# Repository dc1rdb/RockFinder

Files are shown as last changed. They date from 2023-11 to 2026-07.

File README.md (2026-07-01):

## Updates and Project Log
June 30, 2026: Support for Optional Bluetooth module

An optional HC-05 or JDY-33 BT module will allow to transmit CPS data to CurieFinder https://github.com/ATonda/CurieFinder_app
CurieFinder is a field tool designed for localization of radiation sources, mapping areas with elevated activity, prospecting and tracing ore veins.
Latest Arduino sketch located here: https://github.com/dc1rdb/RockFinder/blob/main/software/Rockfinder_digital/Rockfinder_digital.ino

June 26, 2026: Full digital version finally working

The full digital version is finally working satisfactory. The below mentioned analog circuit is no longer required, TTL output of Mini SiD directly connects to GPIO13 (D7 on Wemos D1 mini). Optional sensitivity adjustment via rotary encoder. 

July 30, 2024: Code changes V3.0

- Rotary encoder readout now via ISR
- Real variable gain rather than just threshold adjustment

Dec 8th, 2023: Update 

I`ve just finished a unit that incorporates a rotary encoder for threshold adjustment and utilizes a 40 mm dia x 40 mm NaI(Tl) scintillator coupled to a 2x2 SiPM array (MICROFC-60035-SMT-TR). With around four times the scintillator volume compared to my first unit, the sensitivity is significantly improved. A few pics of the new unit can be found in https://github.com/dc1rdb/RockFinder/tree/main/docs

# RockFinder
Scintillator based detector for prospecting radioactive minerals.
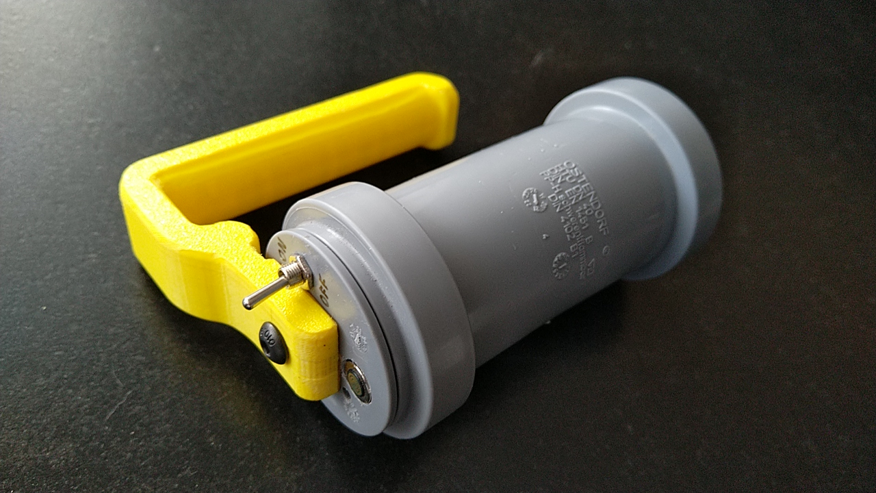
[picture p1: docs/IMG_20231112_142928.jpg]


## Background
When searching for radioactive rocks in the wild, I always found it annoying to keep my eyes on the display of whatever gamma detector I was using. Concentrating on small changes in click rate is also less than ideal.
On the other hand, the human brain / ear can easily and subconciously detect very small variations in tone pitch. For example, this principle is widely used in satellite dish alignment tools.

## Project Overview
This project is an add-on for **Nuclear Phoenix' Mini SiPM Driver (SiD) Board:** https://github.com/OpenGammaProject/Mini-SiD

Please refer to his page for setting up the scintillator and SiPM.

This add-on converts the TTL output pulses from the Mini SiD to a tone signal with variable frequency. The tone frequency increases with the count rate detected by the SiPM. As a result, one can quickly pinpoint the radioactive source / hotspot.

## Specs

* Compact design: Total size 125 x 100 x 55 mm. Weight 275 g
* Low-voltage device: No HV needed like with a photomultiplier tube
* Low power consumption: <50 mA
* Adjustable threshold / sensitivity to cope with different levels of background radiation (optional)

I am currently using a 1" dia x 1" CsI(Tl) encapsulated scintillator from OST Photonics, coupled to a MICROFC-60035-SMT-TR SiPM. The side wall of the scintillator is covered with lead foil to improve directivity.

## Description

Via a few additional passive components, the Trigger/TTL output of the Mini SiD is connected to the analog input of a ESP 8266 programmed as a voltage controlled oscillator. 

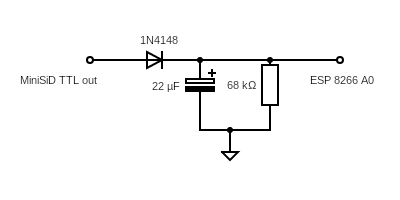
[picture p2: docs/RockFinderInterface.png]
RockFinderInterface


A passive buzzer connected to a GPIO pin of the ESP8266 outputs a tone signal.

Optionally, sensitivity can be adjusted with a rotary encoder.

The ESP8266 is a Lolin D1 Mini Pro with included battery connector and charging circuit. A small single cell 350 mAh LiPo battery sits between the Mini SiD and the veroboard and the Mini SiD is easily being powered via the 3V3 pin of the ESP. This allows for around 6 hours of operation. The LiPo battery is being charged via the USB interface of the ESP8266. A magnetic USB plug is added for better handling. If an internal battery is not required, any ESP8266 clone can be used.

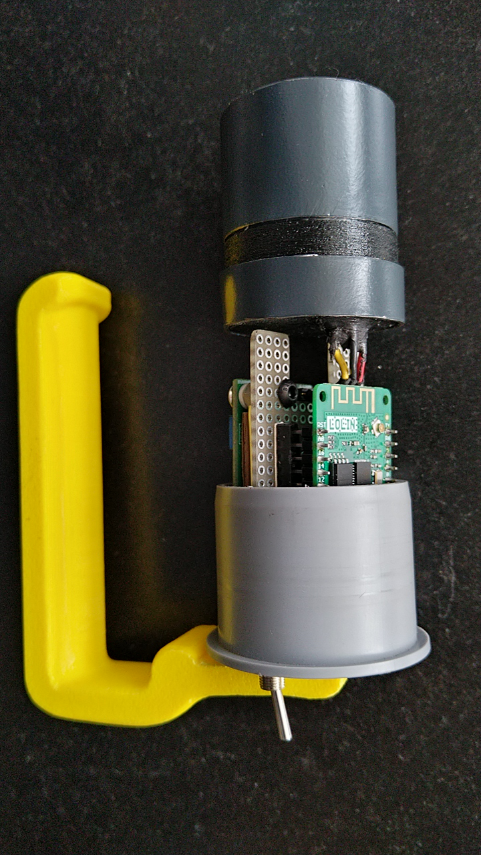
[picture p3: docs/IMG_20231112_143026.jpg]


## Hardware
The enclosure is a standard DN40 (or DN50) tube with end caps, available at home improvement stores. The handle is 3D printed from:
Ludlum 2401 Handle by S0N1C https://www.thingiverse.com/thing:2561532

An endcap to house the SiPM on the window side of the scintillator can be 3D printed with TPU from this file: https://github.com/dc1rdb/RockFinder/blob/main/hardware/SiPM_endcap1inch.stl

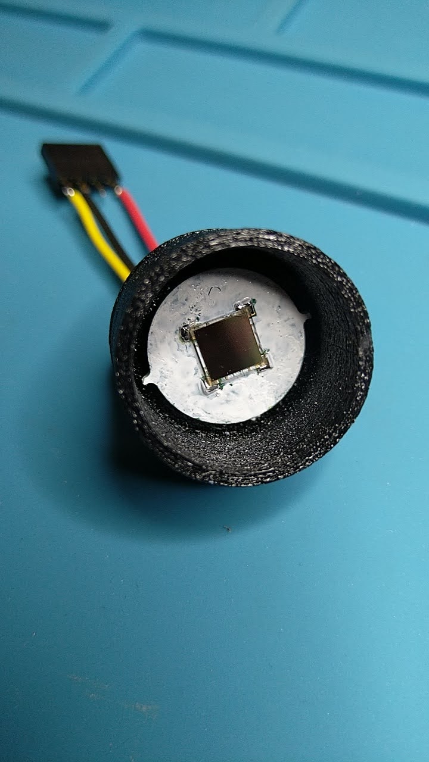
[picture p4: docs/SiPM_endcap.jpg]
SiPM_endcap


## Code
Arduino code in https://github.com/dc1rdb/RockFinder/tree/main/software/RockFinder_analog

## Demo
Video of the prototype in action: https://github.com/dc1rdb/RockFinder/blob/main/docs/RockfinderDemo.mp4

Thanks for reading!

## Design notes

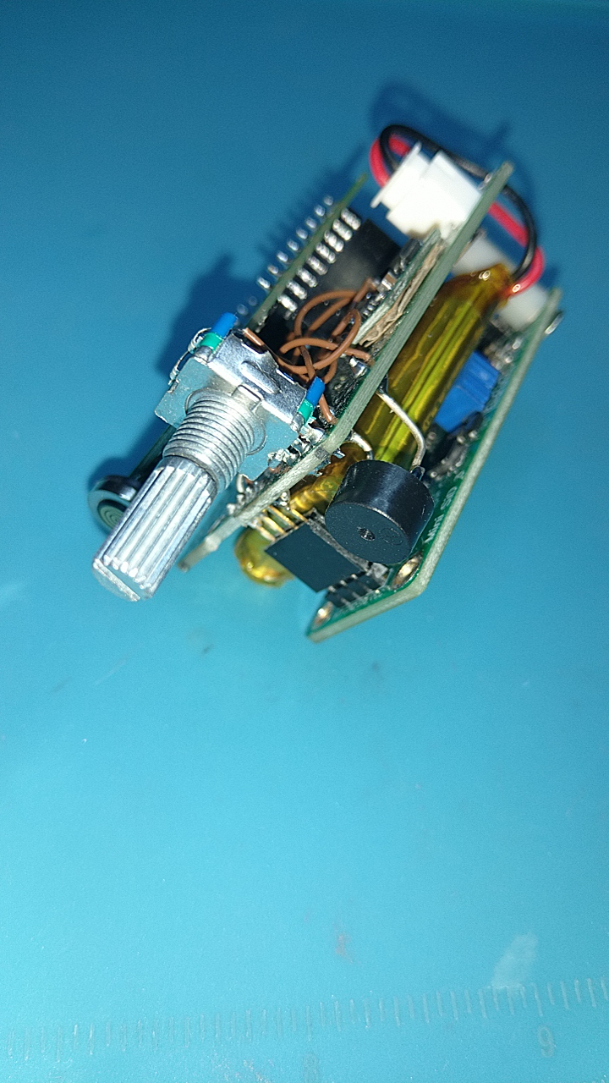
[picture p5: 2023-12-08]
docs/V2_internal1.jpg

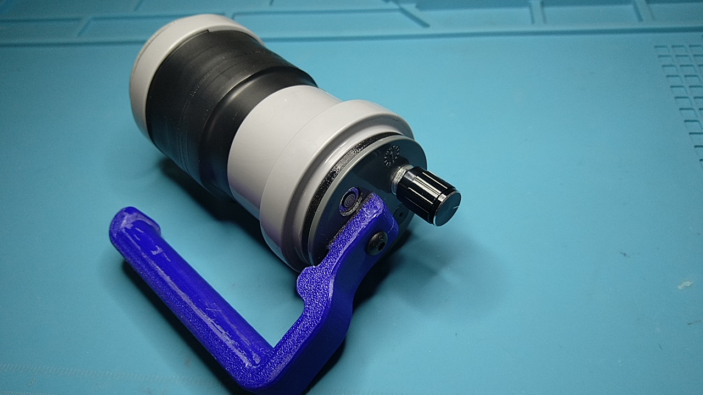
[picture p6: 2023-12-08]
docs/V2_external.jpg

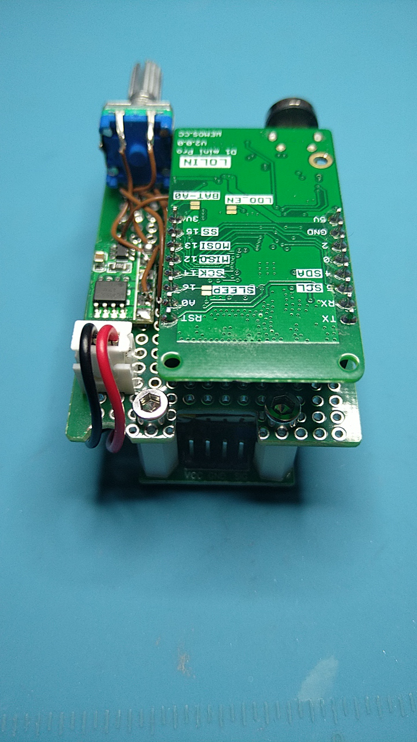
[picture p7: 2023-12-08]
docs/V2_internal2.jpg

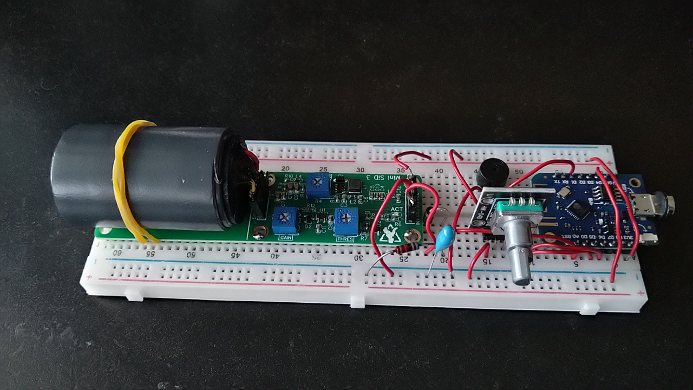
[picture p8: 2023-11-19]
docs/development_unit.jpg

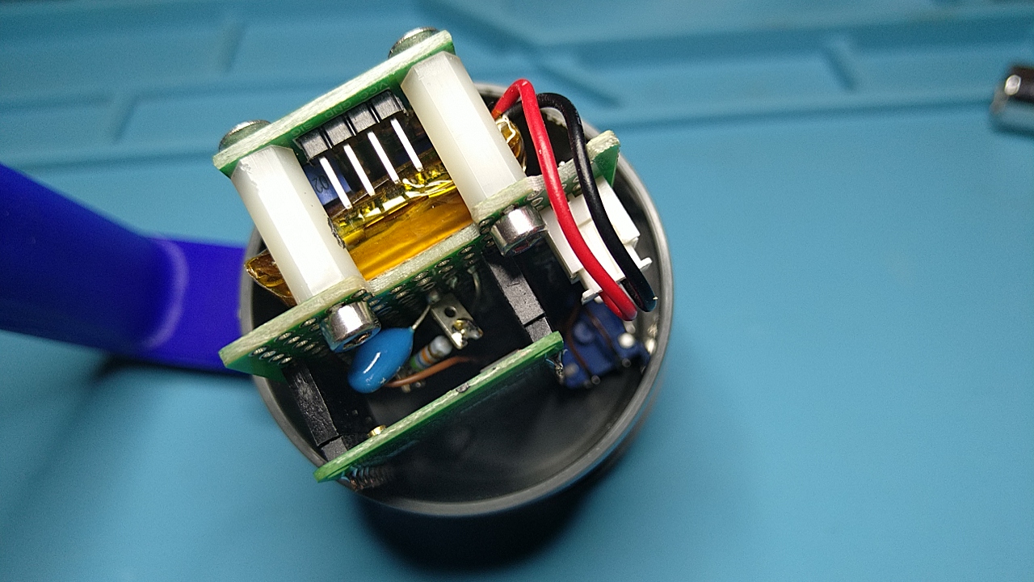
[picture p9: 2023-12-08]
docs/V2_internal3.jpg

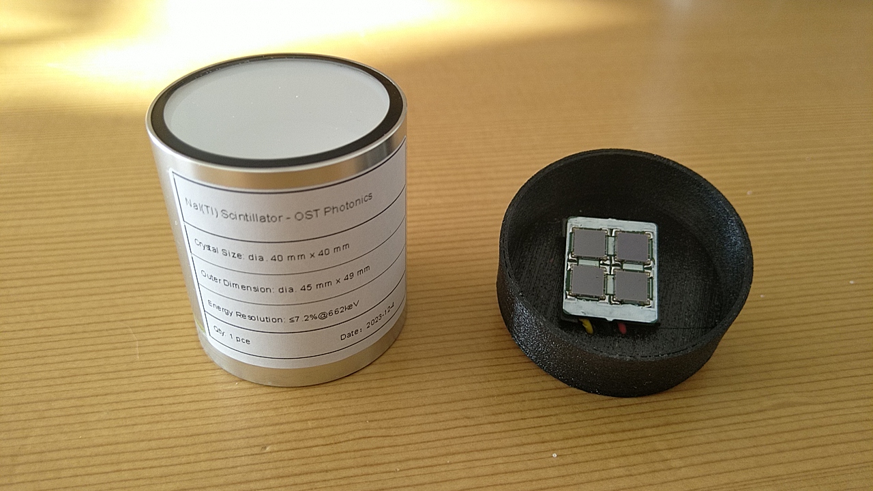
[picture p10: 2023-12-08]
docs/V2_scintillator_and_SiPM_array.jpg

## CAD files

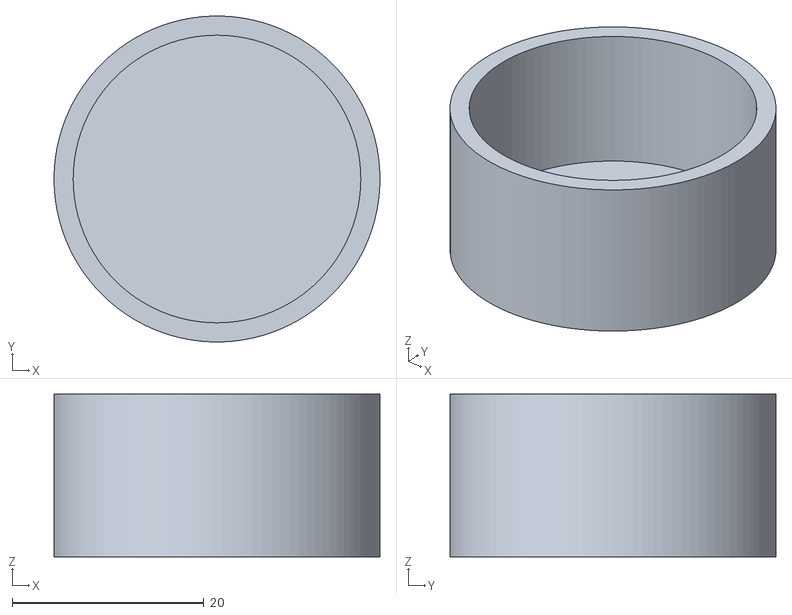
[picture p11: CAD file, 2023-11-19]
hardware/SiPM_endcap1inch.stl
34.0 x 34.0 x 17.0

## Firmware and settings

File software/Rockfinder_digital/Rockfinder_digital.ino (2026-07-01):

/*

Simple detector for gamma radioactive substances,
utilizing a Mini SiPM Driver (SiD) Board https://github.com/OpenGammaProject/Mini-SiD
and a Wemos D1 Mini ESP8266.
Converts Mini-SiD TTL output pulses to continuous moving tone
Optional rotary encoder for sensitivity adjustment
Optional HC-05 or JDY-33 BT module: connect RX to GPIO2  (D4 on Wemos D1 mini)
to transmit CPS data to CurieFinder https://github.com/ATonda/CurieFinder_app

V1.5 - Transmit battery voltage to CurieFinder (solder bridge on Wemos D1 mini required)
     - More filter optimizations

*/

#include <ESP8266WiFi.h>
#include <Arduino.h>

// ============================================================================
// 1. HARDWARE & CONSTANT SETUP
// ============================================================================
const int PULSE_PIN = 13;      // GPIO13 (D7 on Wemos D1 mini)
const int BUZZER_PIN = 5;       // GPIO5  (D1 on Wemos D1 mini)
const int BATTERY_PIN = A0;     // Analog pin A0 for voltage sensing

// Rotary Encoder Pins
const int encoderCLK = 14;     // GPIO14 (D5 on Wemos D1 mini)
const int encoderDT = 12;      // GPIO12 (D6 on Wemos D1 mini)

// HC-05 BT module RX on GPIO2  (D4 on Wemos D1 mini)

// Timing Rules
const unsigned long UPDATE_INTERVAL = 100;    //how often cps value is being calculated
unsigned long lastUpdateTime = 0;

// Bluetooth Timing Configuration
const unsigned long BT_INTERVAL = 200;       //how often data is being sent via Bluetooth
unsigned long lastBTTime = 0;             

// Global storage for the latest averaged value to share across loops
float globalFilteredCPS = 0.0;

// ============================================================================
// 2. SIGNAL FILTER & CONTROL CONFIGURATION
// ============================================================================
// Adaptive EMA Configuration
float emaFilteredCPS = 0.0;        
const float ALPHA_MIN = 0.05f;          //smoothing coefficient for stable baselines
const float ALPHA_MAX = 0.50f;          //response coefficient for rapid spikes
const float SENSITIVITY_SCALE = 0.007f;  //controls how aggressively alpha reacts to deviation

// Buzzer Frequency Boundaries (Hz)
const int MIN_FREQ = 30;                 //buzzer frequency at background radiation
const int MAX_FREQ = 5000;               //max buzzer frequency 

// Audio Glide Engine Constants
const float PITCH_GLIDE = 0.01f;        //"flywheel" for tone pitch changes
float targetPitch = MIN_FREQ;           
float activePitch = MIN_FREQ;           
int lastEmittedPitch = 0;            

// Dynamic Sensitivity Tuning
const int MIN_CPS = 50;              //background cps, higher value for larger scintillator     
volatile int maxCPSCeiling = 1000;   //adjust this for desired fixed sensitivity if no rotary encoder used
const int MIN_CEILING = 1000;        
const int MAX_CEILING = 15000;      
const int ENCODER_STEP = 1000;       

// Interrupt Storage
volatile unsigned long pulseCount = 0;

// Optimized State Machine Array for Quadrature Encoding (Prevents Ghost Steps)
// Maps 4-bit indices [OldCLK, OldDT, NewCLK, NewDT] to valid step actions (-1, 0, 1)
const int8_t KNOB_STATES[] = {0, -1, 1, 0, 1, 0, 0, -1, -1, 0, 0, 1, 0, 1, -1, 0};
volatile uint8_t encoderHistory = 0;

// Compile-time pre-calculation
const float CPS_MULTIPLIER = 1000.0f / (float)UPDATE_INTERVAL;

// ============================================================================
// 3. INTERRUPT SERVICE ROUTINES (ISRs)
// ============================================================================
void ICACHE_RAM_ATTR countPulse() {
  pulseCount++;
}

// State Machine Decoder running on CHANGE for BOTH pins
void ICACHE_RAM_ATTR readEncoder() {
  encoderHistory = (encoderHistory << 2) & 0x0F;
  encoderHistory |= (digitalRead(encoderCLK) << 1) | digitalRead(encoderDT);
  
  int8_t movement = KNOB_STATES[encoderHistory];
  static int8_t subStepCounter = 0;
  
  if (movement != 0) {
    if (movement > 0) {
      subStepCounter--;
    } else {
      subStepCounter++;
    }
    
    if (subStepCounter >= 4) {
      subStepCounter = 0; 
      maxCPSCeiling += ENCODER_STEP;
      if (maxCPSCeiling > MAX_CEILING) maxCPSCeiling = MAX_CEILING;
    } 
    else if (subStepCounter <= -4) {
      subStepCounter = 0; 
      maxCPSCeiling -= ENCODER_STEP;
      if (maxCPSCeiling < MIN_CEILING) maxCPSCeiling = MIN_CEILING;
    }
  }
}

// ============================================================================
// 4. HELPER FUNCTIONS
// ============================================================================
float getAdaptiveEMA(float newVal) {
  float diff = abs(newVal - emaFilteredCPS);
  float alpha = ALPHA_MIN + (diff * SENSITIVITY_SCALE);
  alpha = constrain(alpha, ALPHA_MIN, ALPHA_MAX);
  emaFilteredCPS = (newVal * alpha) + (emaFilteredCPS * (1.0f - alpha));
  return emaFilteredCPS;
}

// Reads analog pin with 8x oversampling to stabilize jitter
int getBatteryVoltage() {
  long adcSum = 0;
  for(int i = 0; i < 8; i++) {
    adcSum += analogRead(BATTERY_PIN);
    delayMicroseconds(50); 
  }
  float avgADC = (float)adcSum / 8.0f;
  
  // Max range is 4500mV (at 1023 raw). 4500 / 1023 = 4.39882
  int millivolts = (int)(avgADC * 4.39882f);
  return millivolts;
}

// ============================================================================
// 5. SYSTEM INITIALIZATION
// ============================================================================
void setup() {
  Serial.begin(115200);
  Serial1.begin(9600); 
  
  WiFi.persistent(false);
  WiFi.mode(WIFI_OFF);
  WiFi.forceSleepBegin();   
  
  pinMode(PULSE_PIN, INPUT); 
  pinMode(BUZZER_PIN, OUTPUT);
  pinMode(encoderCLK, INPUT_PULLUP);
  pinMode(encoderDT, INPUT_PULLUP);
  
  encoderHistory = (digitalRead(encoderCLK) << 1) | digitalRead(digitalRead(encoderDT));
  
  attachInterrupt(digitalPinToInterrupt(PULSE_PIN), countPulse, RISING);
  attachInterrupt(digitalPinToInterrupt(encoderCLK), readEncoder, CHANGE);
  attachInterrupt(digitalPinToInterrupt(encoderDT), readEncoder, CHANGE);
}

// ============================================================================
// 6. MAIN EXECUTION LOOP
// ============================================================================
void loop() {
  unsigned long currentTime = millis();
  
  // --------------------------------------------------------------------------
  // BLOCK A: DATA SAMPLING
  // --------------------------------------------------------------------------
  if (currentTime - lastUpdateTime >= UPDATE_INTERVAL) {
    lastUpdateTime = currentTime; 
    
    noInterrupts();
    unsigned long pulsesSampled = pulseCount;
    pulseCount = 0;
    int localCeiling = maxCPSCeiling; 
    interrupts();
    
    float instantCPS = pulsesSampled * CPS_MULTIPLIER;
    globalFilteredCPS = getAdaptiveEMA(instantCPS);
    
    targetPitch = map((int)globalFilteredCPS, MIN_CPS, localCeiling, MIN_FREQ, MAX_FREQ);
    targetPitch = constrain(targetPitch, MIN_FREQ, MAX_FREQ);

    Serial.print("Raw CPS: "); 
    Serial.print(instantCPS, 1);
    Serial.print(" | Adaptive EMA CPS: "); 
    Serial.print(globalFilteredCPS, 1);
    Serial.print(" | Tone Range Top: ");
    Serial.print(localCeiling);
    Serial.println(" CPS");
  }

  // --------------------------------------------------------------------------
  // BLOCK B: BLUETOOTH DATA TRANSMISSION
  // --------------------------------------------------------------------------
  if (currentTime - lastBTTime >= BT_INTERVAL) {
    lastBTTime = currentTime;
    
    int currentVbat = getBatteryVoltage();
    
    // Prints requested format: CPS=x.xx VBAT=xxxxmV
    Serial1.print("CPS=");
    Serial1.print(globalFilteredCPS, 2);
    Serial1.print(" VBAT=");
    Serial1.print(currentVbat);
    Serial1.println("mV"); 
  }

  // --------------------------------------------------------------------------
  // BLOCK C: CONTINUOUS AUDIO ENGINE 
  // --------------------------------------------------------------------------
  activePitch = activePitch + ((targetPitch - activePitch) * PITCH_GLIDE);
  int currentIntPitch = (int)activePitch;
  
  if (currentIntPitch != lastEmittedPitch) {
    tone(BUZZER_PIN, currentIntPitch);
    lastEmittedPitch = currentIntPitch;
  }
}

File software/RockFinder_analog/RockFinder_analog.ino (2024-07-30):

/*

Simple detector for gamma radioactive substances,
utilizing a Mini SiPM Driver (SiD) Board
https://github.com/OpenGammaProject/Mini-SiD
and a Wemos D1 Mini ESP8266. This sketch
is basically a voltage controlled oscillator (VCO)
from analog input A0 and outputs an audio frequency
tone to a passive buzzer.

V3.0 - July 30, 2024
- Rotary encoder readout is now an interrupt service routine
- real variable gain rather than just threshold adjustment

Dependencies:
RotaryEncoder by Matthias Hertel

*/

#include <ESP8266WiFi.h>
#include <RotaryEncoder.h>

#define MIN 50                  //minimum output tone frequency (Hz)
#define MAX 5000                //maximum output tone frequency (Hz)
#define buzzerPin D1            //passive buzzer between this pin and GND

#define PIN_IN1 D6              //rotary encoder DT
#define PIN_IN2 D5              //rotary encoder CLK

#define LATCHMODE FOUR3         //LatchMode FOUR3 or TWO03, depending on encoder type
#define ROTARYSTEPS 1           //step width for gain adjustment
#define ROTARYMIN 1             //minimum gain value
#define ROTARYMAX 10            //maximum gain value
#define INI 10                  //initial gain value (or fixed gain if no encoder is connected)
#define THR 100                 //threshold to suppress SIPM noise

RotaryEncoder *encoder = nullptr;

IRAM_ATTR void checkPosition()
{
  encoder->tick();              // just call tick() to check the state.
}

void setup() {
  // Serial.begin(115200);         //debug only
  WiFi.mode(WIFI_OFF);          //turn off WIFI to reduce ESP8266 power consumption
  delay(1000);
  
  encoder = new RotaryEncoder(PIN_IN1, PIN_IN2, RotaryEncoder::LatchMode::LATCHMODE);
  encoder->setPosition(INI / ROTARYSTEPS);
  
  attachInterrupt(digitalPinToInterrupt(PIN_IN1), checkPosition, CHANGE);
  attachInterrupt(digitalPinToInterrupt(PIN_IN2), checkPosition, CHANGE);

  pinMode(buzzerPin, OUTPUT);
  
}

void loop() {
  
  encoder->tick();              // just call tick() to check the state.

   int GAIN = encoder->getPosition() * ROTARYSTEPS;

  if (GAIN < ROTARYMIN) {
    encoder->setPosition(ROTARYMIN / ROTARYSTEPS);
    GAIN = ROTARYMIN;
  } 
  
  else if (GAIN > ROTARYMAX) {
    encoder->setPosition(ROTARYMAX / ROTARYSTEPS);
    GAIN = ROTARYMAX;
  } 

    // Serial.print(GAIN);        //debug only
    // Serial.println();          //debug only

  //output tone to buzzer
  uint16_t frequencyinput = analogRead(A0) * GAIN;
  uint16_t outputfrequency = map(frequencyinput, (THR * GAIN / 2), 10230, MIN, MAX);
  tone(buzzerPin, outputfrequency);
  
  delay(10);
}

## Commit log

2023-12-08 Update RockFinder_analog.ino
    Encoder latch mode
2024-07-30 Update RockFinder_analog.ino
    - Rotary encoder readout is now an interrupt service routine
    - real variable gain rather than just threshold adjustment
2026-06-27 Update Rockfinder_digital.ino
    Boundary alert functionality removed, encoder debouncing added
2026-06-28 Update Rockfinder_digital.ino
    Adaptive exponential moving average filter
    Support for HC-05 Bluetooth module
2026-06-29 Update Rockfinder_digital.ino
    - BT module on hardware Serial1 for improved performance
    - Fixed rotary encoder bouncing & skipping steps
    - Filter optimizations
    [Rockfinder_digital.ino]
2026-07-01 Update Rockfinder to V1.5 with battery support
    Updated version to V1.5 with battery transmission feature and filter optimizations. Adjusted sensitivity parameters and timing intervals for improved performance.
2026-07-01 Revise README for clarity and updates
    Updated README with latest Arduino sketch link and removed redundant information about analog circuit.
2026-07-01 Update version description to specify battery voltage
2026-07-01 Clarify buzzer frequency constants with comments
    Added comments to clarify buzzer frequency constants.
    [Rockfinder_digital.ino]
